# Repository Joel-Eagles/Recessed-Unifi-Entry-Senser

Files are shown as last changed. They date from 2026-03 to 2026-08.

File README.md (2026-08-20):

# Recessed-Unifi-Entry-Senser
A redesigned case for the Ubiquiti SuperLink Entry Sensor. Made to recess the sensor and magnet into the door and frame.

Update: Looks like Ubiquiti saw this and got some ideas. [Click Here](https://store.ui.com/us/en/products/usl-entry-r) to buy the official version

[Click here for IFixit disassembly guide](https://www.ifixit.com/Guide/Ubiquiti+Unifi+Entry+Sensor+%7C+USL-Entry/211997) (Backup is [here](https://github.com/Joel-Eagles/Recessed-Unifi-Entry-Senser/blob/main/DisassemblyGuideBackup.pdf) if unavailable)
<br>
[Click here for the assembly guide](https://github.com/Joel-Eagles/Recessed-Unifi-Entry-Senser/blob/main/Assembly.md)
<br>
[Click here for the installation guide](https://github.com/Joel-Eagles/Recessed-Unifi-Entry-Senser/blob/main/Installation.md)
<br>
[Click here for the onshape source files link](https://cad.onshape.com/documents/9fa11942b709e8cb276eebe3/w/9a96be1a4735a4b981f442b0/e/f783b6d7ffa51d6eca0f374d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)
<br>
[Click here for pre-sliced printable GCode](https://github.com/Joel-Eagles/Recessed-Unifi-Entry-Senser/blob/main/Printable%20STLs/AllParts.gcode.3mf)
<br>
[Click here to download printable STLs](https://github.com/Joel-Eagles/Recessed-Unifi-Entry-Senser/releases/latest/download/allparts.zip)
<br>
[Click here to view the printable files](https://github.com/Joel-Eagles/Recessed-Unifi-Entry-Senser/tree/main/Printable%20STLs)

<br>
<br>

<p>
	
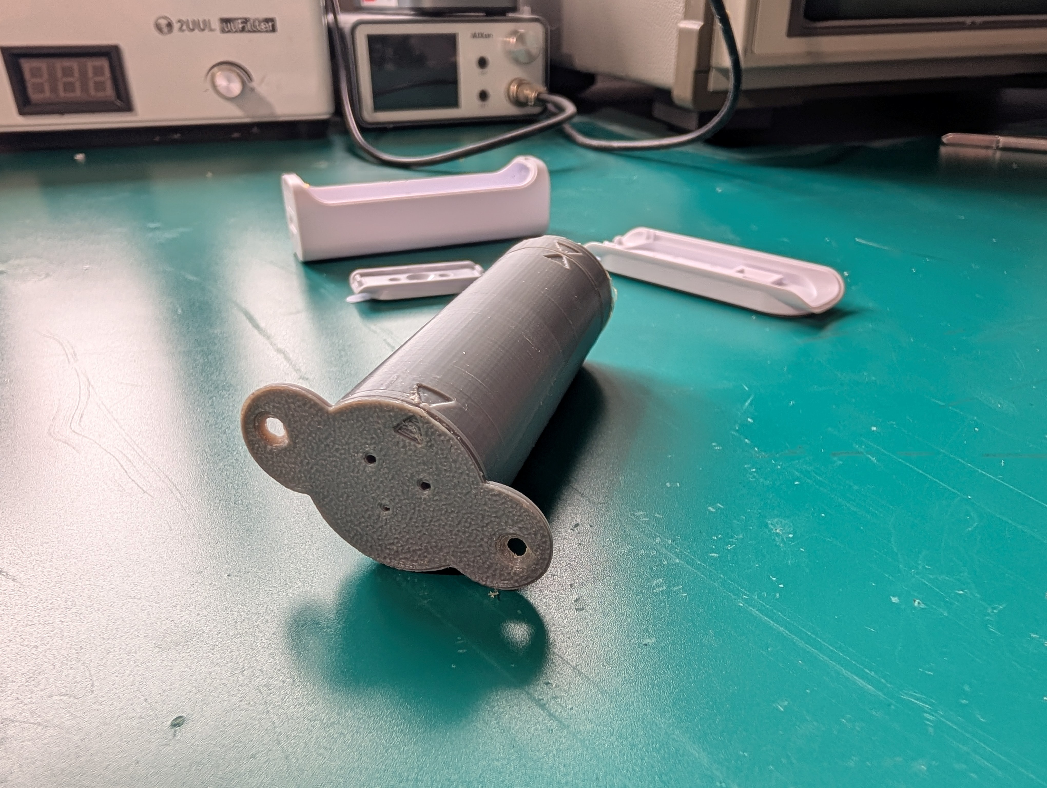
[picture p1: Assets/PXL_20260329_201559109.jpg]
	
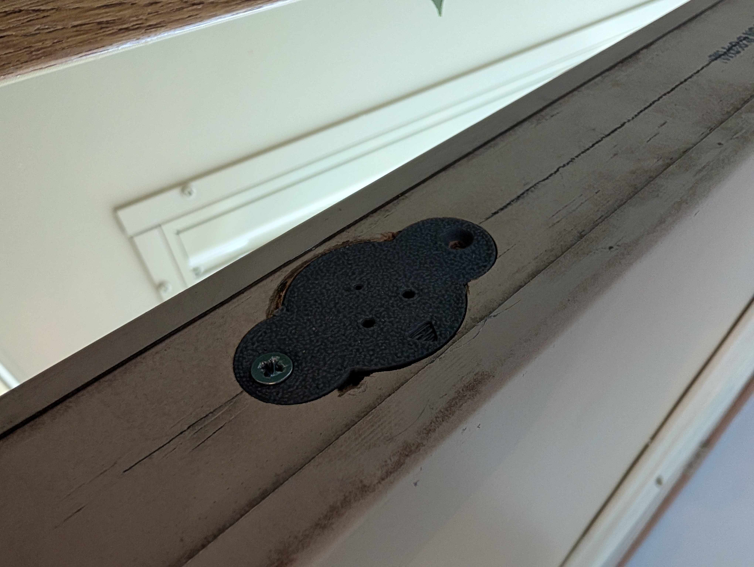
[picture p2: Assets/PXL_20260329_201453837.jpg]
	
</p>

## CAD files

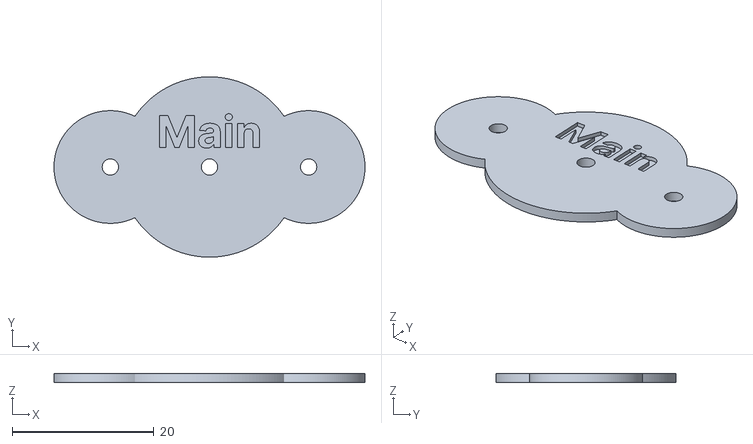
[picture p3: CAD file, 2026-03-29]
Printable STLs/Individual Models/Templates/Main Chassis Template.stl
43.8 x 25.4 x 1.27

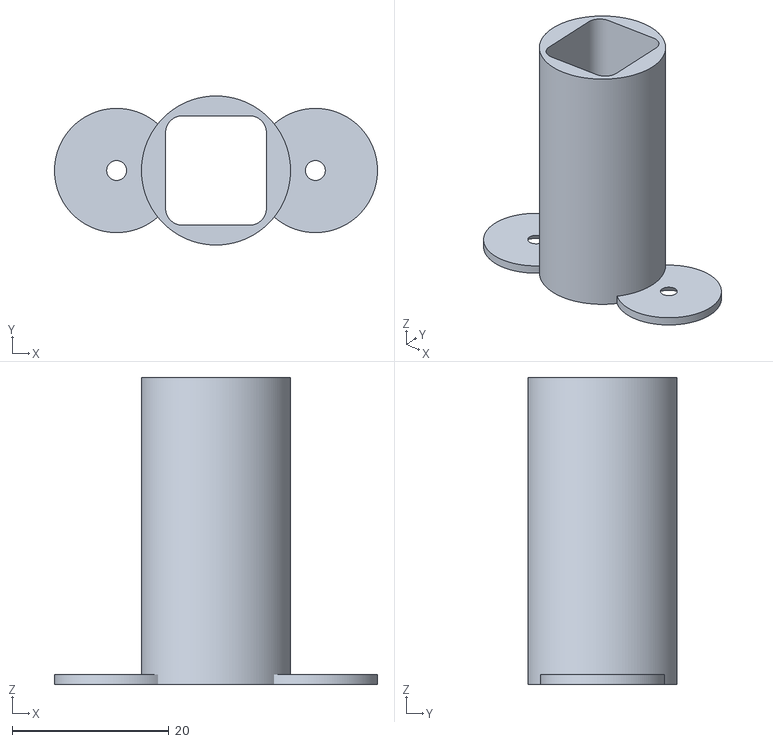
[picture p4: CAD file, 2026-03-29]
Printable STLs/Individual Models/MagnetCase.stl
41.3 x 19.1 x 39.2

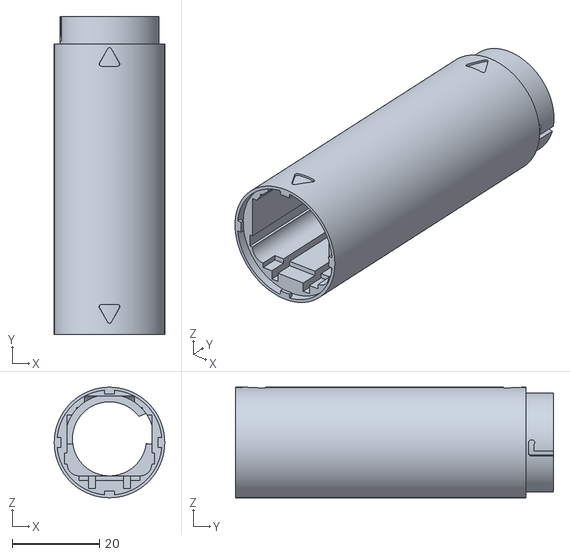
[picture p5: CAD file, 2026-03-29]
Printable STLs/Individual Models/Case.stl
25.4 x 73.1 x 25.4

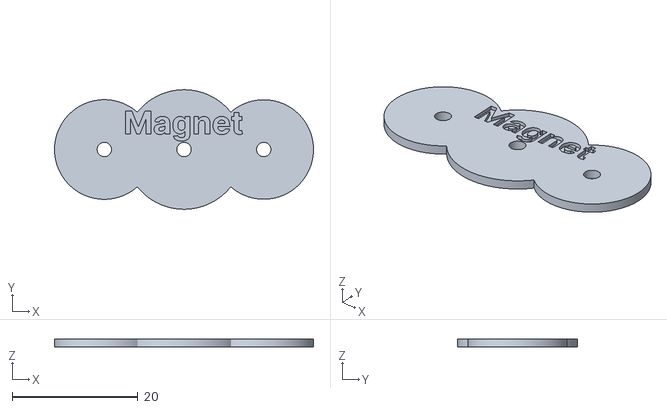
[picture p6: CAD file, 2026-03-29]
Printable STLs/Individual Models/Templates/Magnet Template.stl
41.3 x 19.0 x 1.27

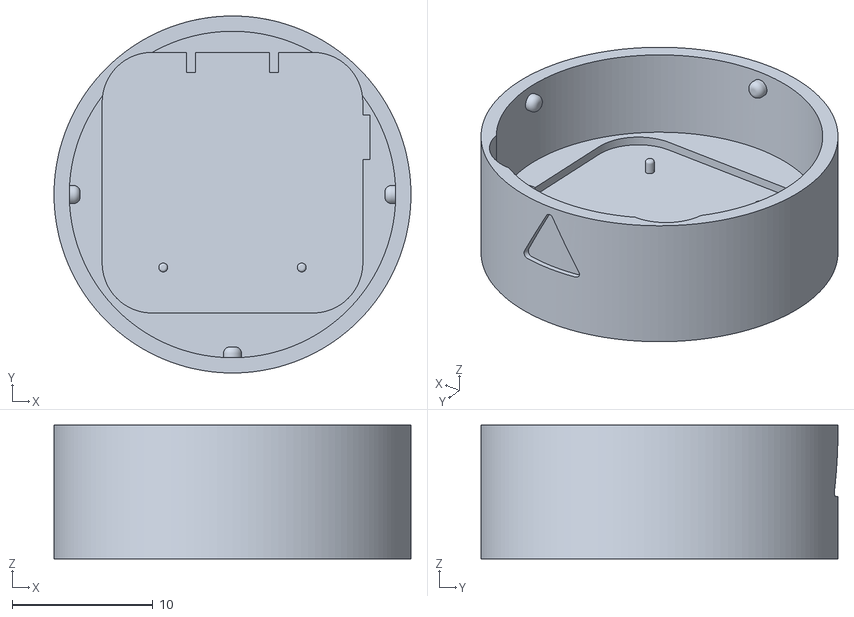
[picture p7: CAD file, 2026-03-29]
Printable STLs/Individual Models/BatteryCap.stl
25.4 x 25.4 x 9.53

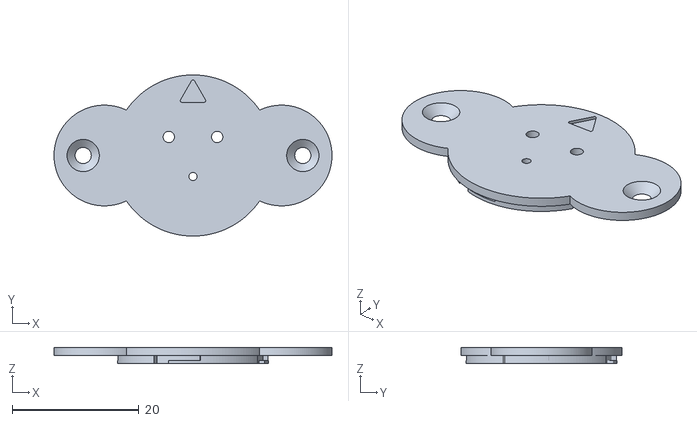
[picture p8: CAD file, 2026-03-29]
Printable STLs/Individual Models/FrontCap.stl
43.8 x 25.4 x 2.54

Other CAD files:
Printable STLs/AllParts.gcode.3mf

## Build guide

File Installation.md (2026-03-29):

[Click here to go home](https://github.com/Joel-Eagles/Recessed-Unifi-Entry-Senser/tree/main)

[Click here for assembly guide](https://github.com/Joel-Eagles/Recessed-Unifi-Entry-Senser/blob/main/Assembly.md)

<br>
<br>

- Mark a centerline along the top of your door
- Align the "Main" Template so that all 3 holes line up with the centerline
  - It is best to position the sensor close to the opening side of the door. This makes it more sensitive to the door opening
- Mark the center point of the 3 circles with a pencil
  - Measure and note the distance from the edge of the door to the center mark. this will be used to position the magnet later. 

<p>
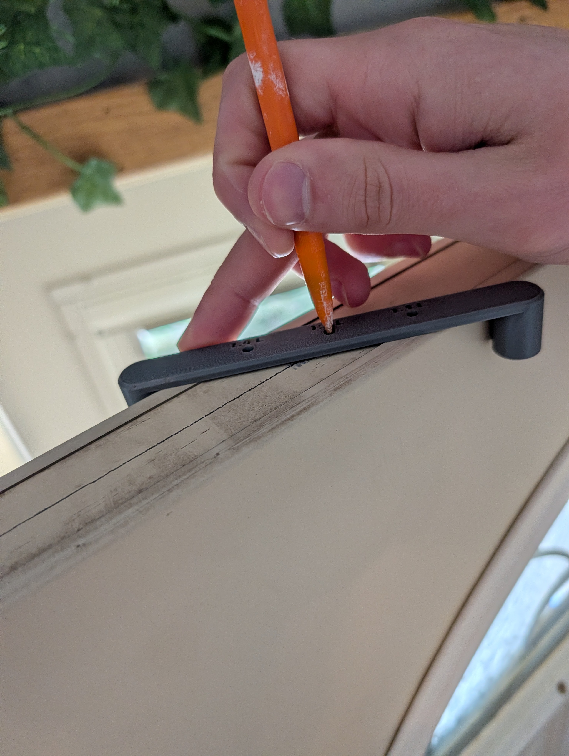
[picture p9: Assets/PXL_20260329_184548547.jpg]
	
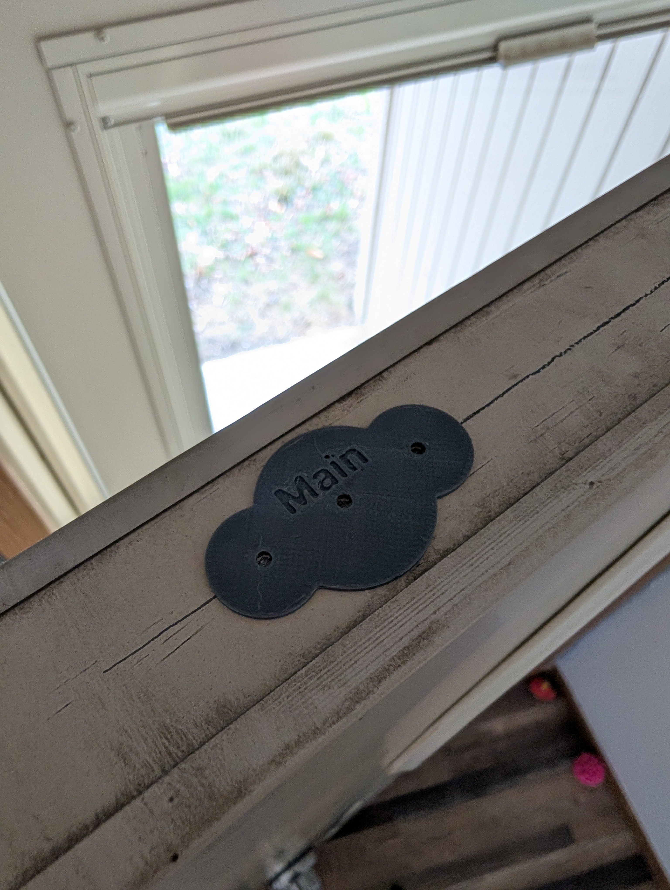
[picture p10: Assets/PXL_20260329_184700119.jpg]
	
</p>

<br>

- With a 5/8" forstner bit, drill on the two outside marks, leaving the 1 in the middle
  - These only need drilled enough to recess the cap into the door, only .05" or about 3/64
  - If you don't mind the look, and your door gap has room for it, you dont have to recesss the cap, and you can skip this step

<p>
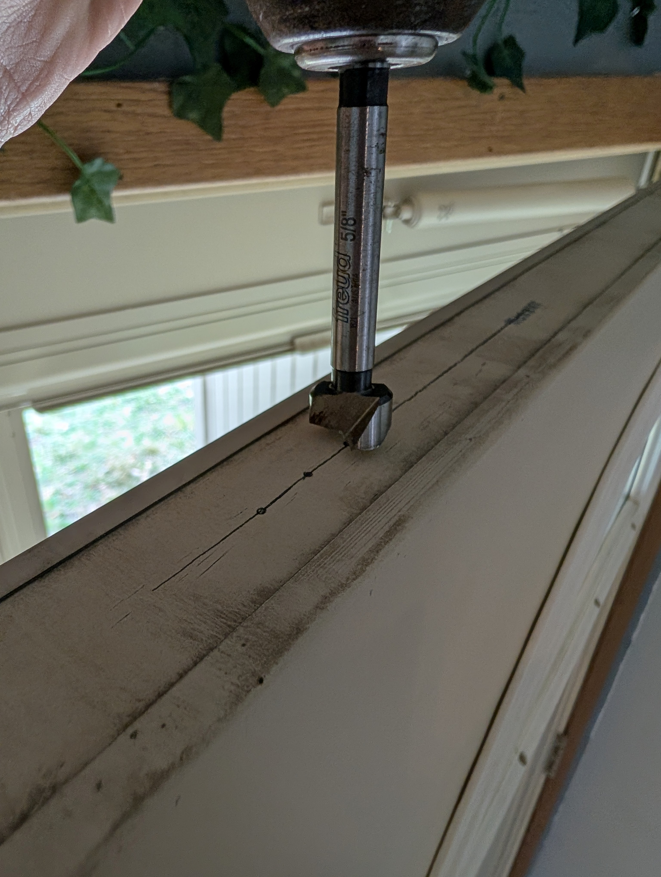
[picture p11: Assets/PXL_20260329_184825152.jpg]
	
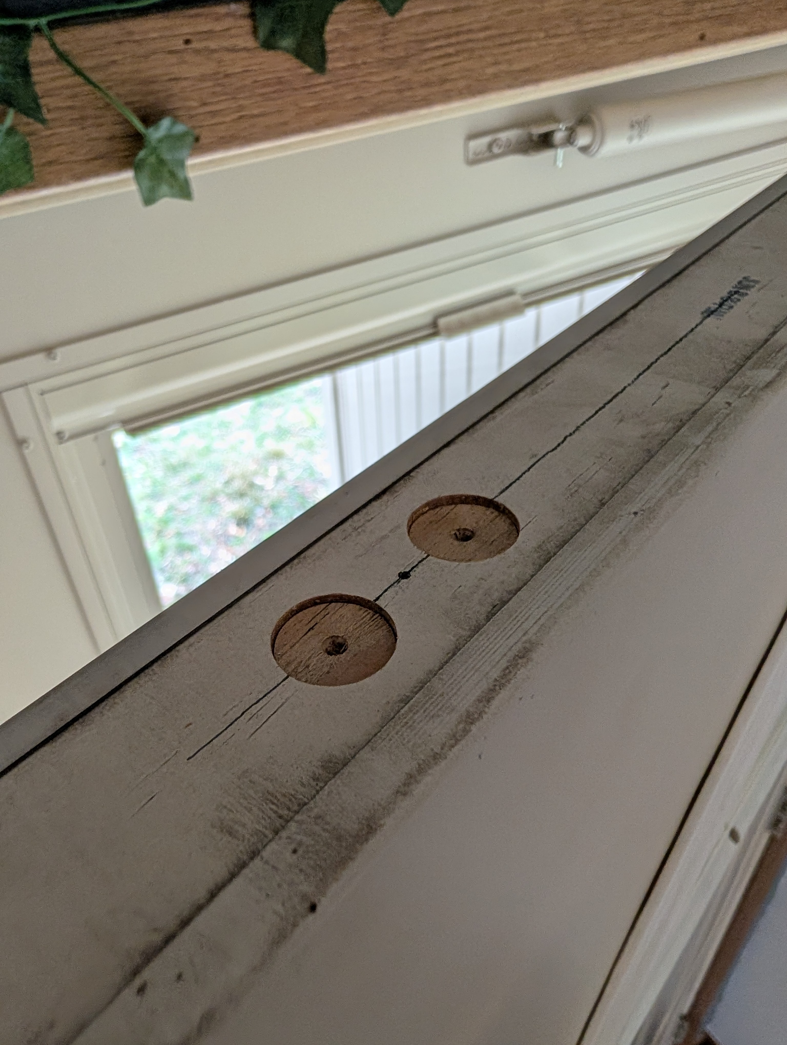
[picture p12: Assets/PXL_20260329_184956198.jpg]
	
</p>

<br>

- With a 1" forstner bit, dill out the center mark.
  - mark the depth you need to drill by lining up the sensor case with your drill bit and mark the end with a tape flag (add a small amount extra for safety).

<p>
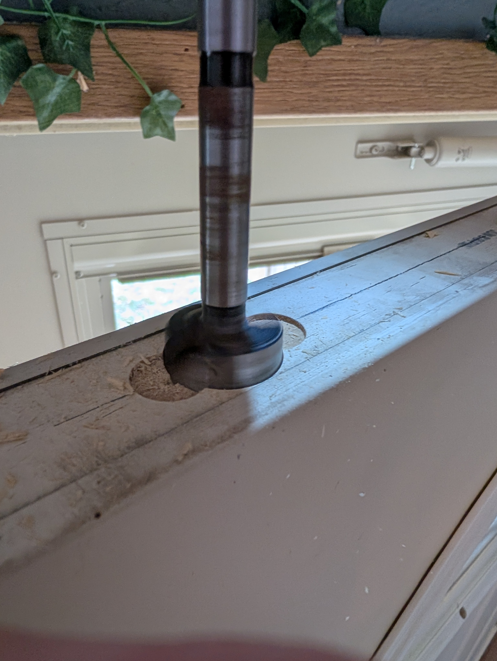
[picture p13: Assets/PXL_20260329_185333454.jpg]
	
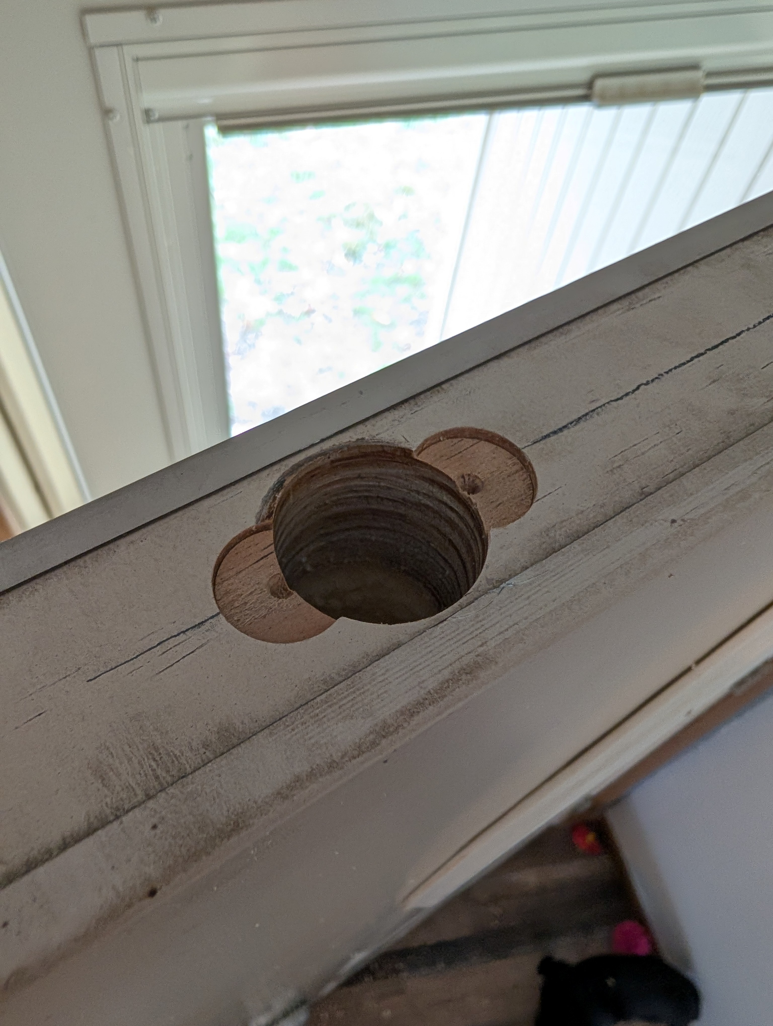
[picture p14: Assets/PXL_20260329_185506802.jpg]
	
</p>

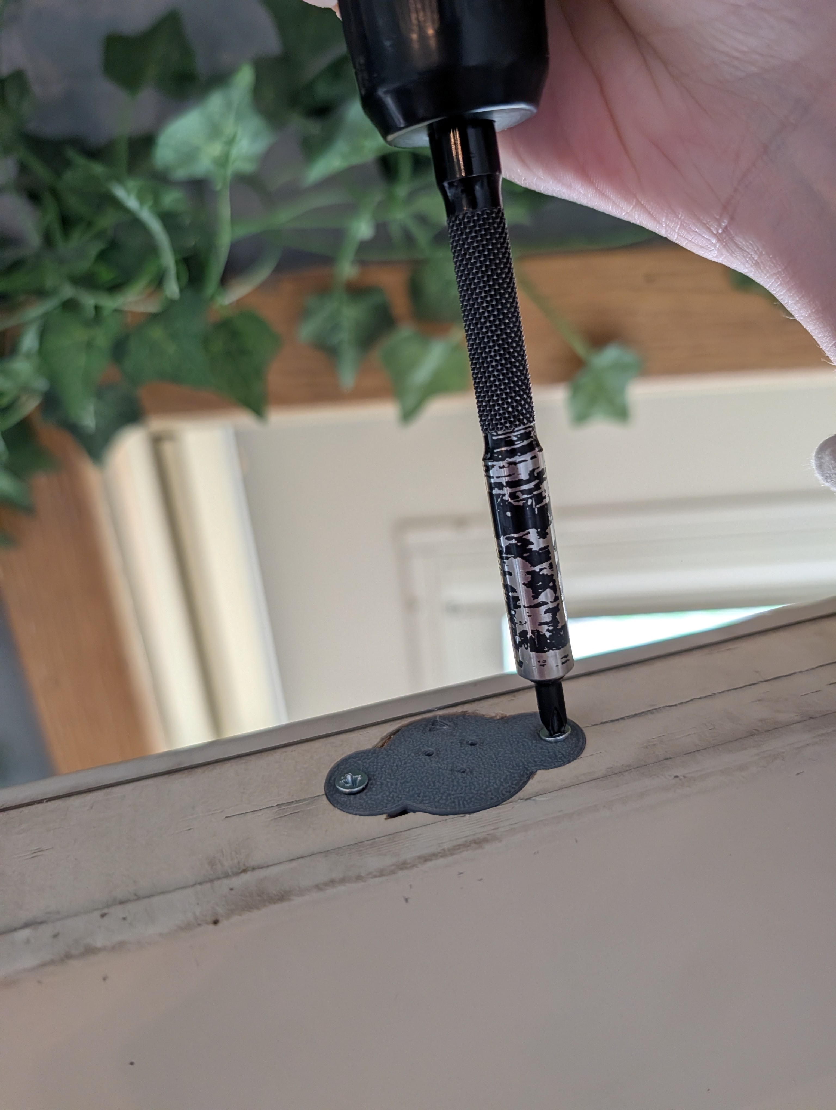
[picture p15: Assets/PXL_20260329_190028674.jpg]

<br>
<br>
<br>
<br>
<br>
<br>

- Slide in sensor and screw in through the ears.
  - I used some #4x1/2" wood screws for this

<br>
<br>
<br>
<br>
<br>
<br>
<br>
<br>
<br>

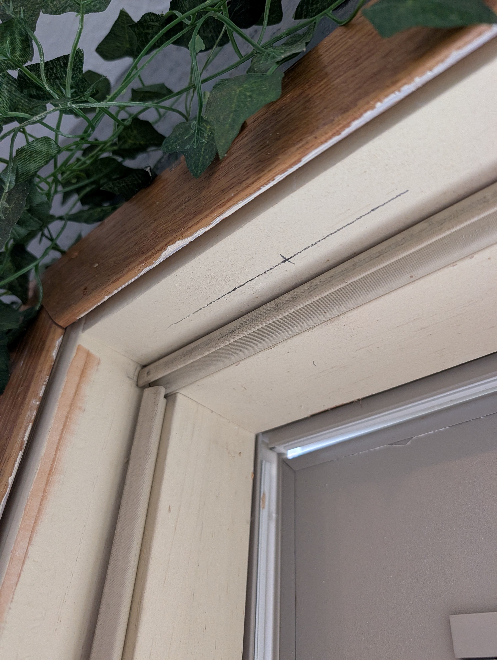
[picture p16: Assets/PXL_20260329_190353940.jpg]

<br>
<br>
<br>
<br>
<br>
<br>

- Take the sensor's distance from the outside face of your door (should be half the thickness of your door). Mark this on the top of the door casing off of the door stop molding
- Take the distance from of the edge of the door and add the width of your door's gaps (close the door and measure the distance from the door edge to the door casing). mark this distance on the top of the door casing off of the door jam.

<br>
<br>
<br>
<br>
<br>
<br>
<br>
<br>
<br>

- Align the center hole of the "Magnet" template with the intersecting lines you just marked on the top of the door casing.
- mark the 2 outer circle centers

  <p>
	
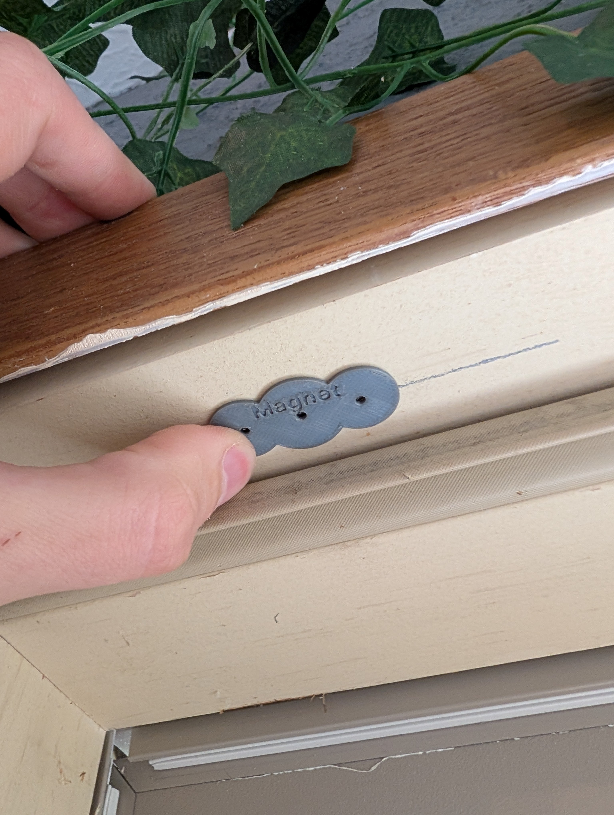
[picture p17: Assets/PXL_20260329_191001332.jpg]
	
</p>

<br>

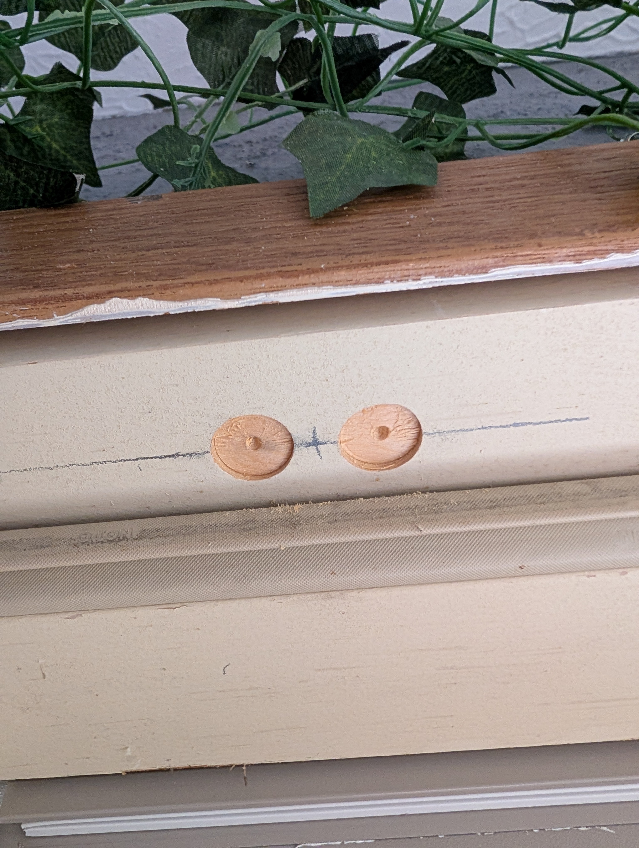
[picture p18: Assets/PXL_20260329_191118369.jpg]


<br>
<br>
<br>
<br>
<br>
<br>

- With a 5/8" forstner bit, drill on the two outside marks, leaving the 1 in the middle
  - These only need drilled enough to recess the cap into the door, only .05" or about 3/64
  - If you don't mind the look, and your door gap has room for it, you dont have to recesss the cap. and you can skip this step

<br>
<br>
<br>
<br>
<br>
<br>
<br>
<br>

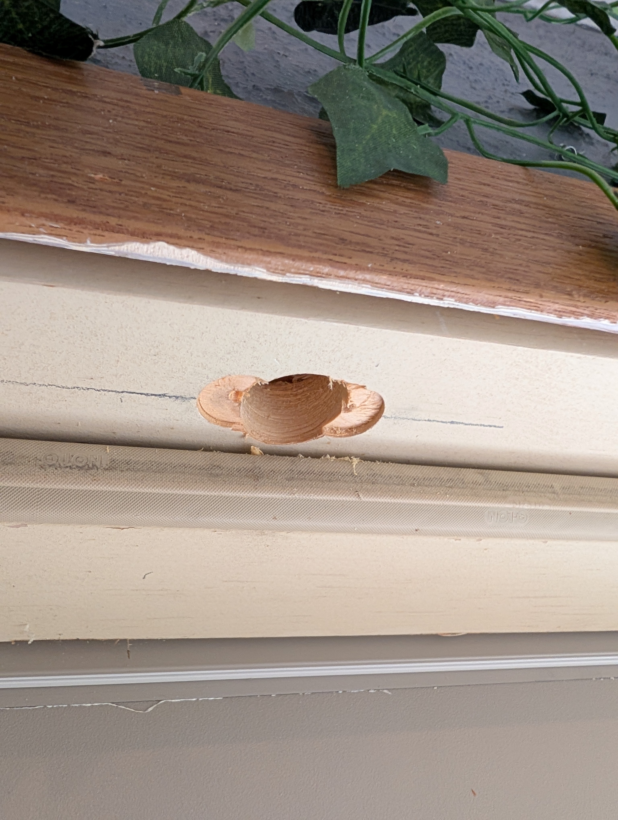
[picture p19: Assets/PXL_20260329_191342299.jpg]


<br>
<br>
<br>
<br>

- With a 3/4" forstner bit, dill out the center mark.
  - mark the depth you need to drill by lining up the magnet case with your drill bit and mark the end with a tape flag (add a small amount extra for safety).

<br>
<br>
<br>
<br>
<br>
<br>
<br>
<br>
<br>

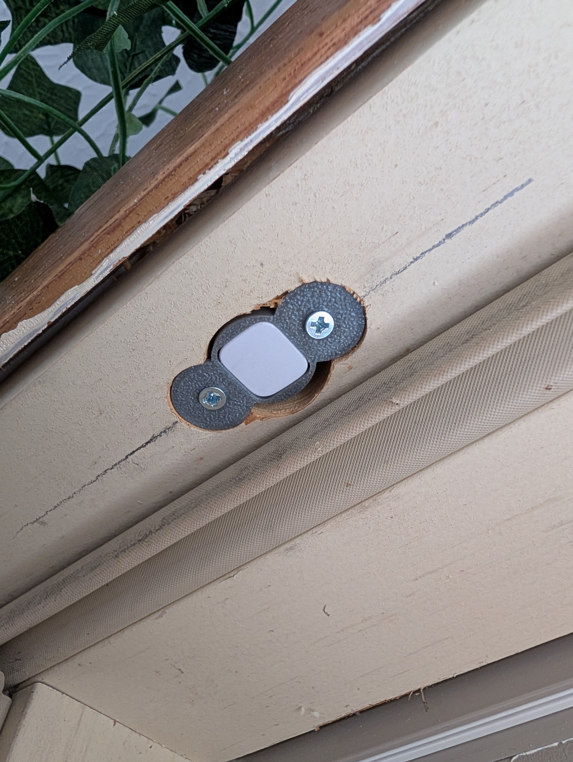
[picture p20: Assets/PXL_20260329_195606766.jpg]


<br>
<br>
<br>
<br>
<br>
<br>

- Slide in Magnet and screw in through the ears.
  - I used some #4x1/2" wood screws for this

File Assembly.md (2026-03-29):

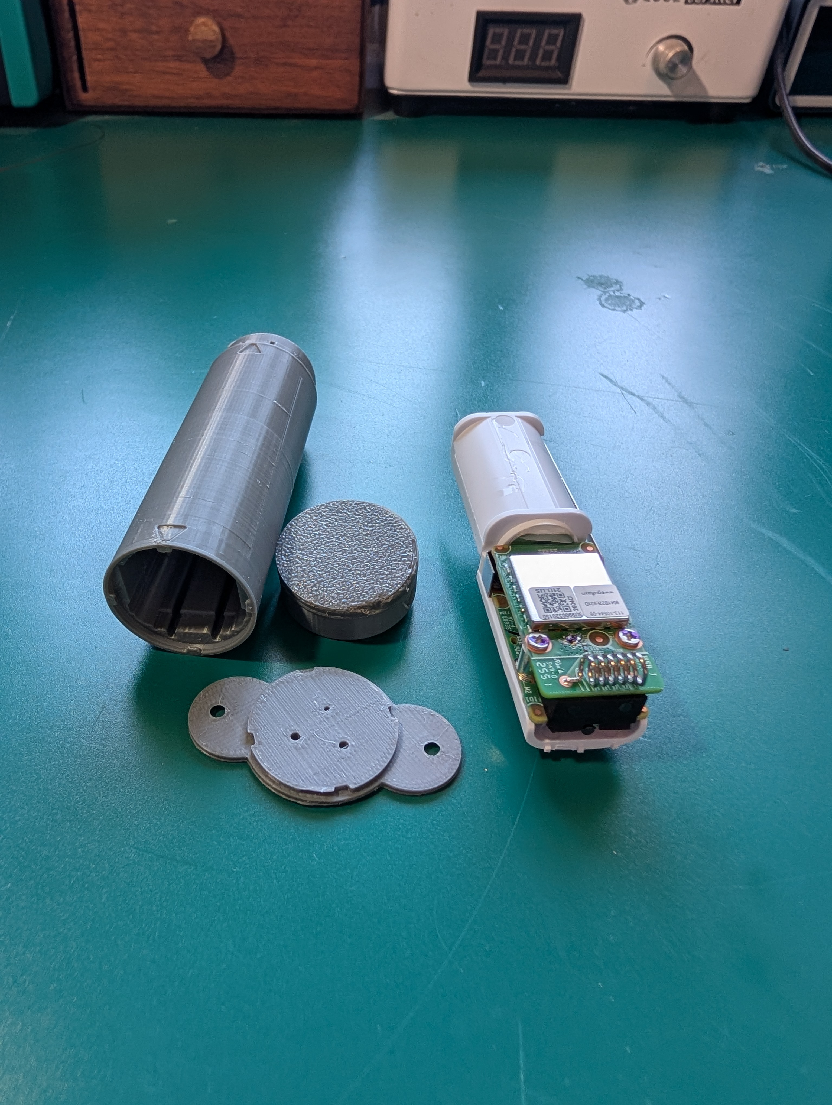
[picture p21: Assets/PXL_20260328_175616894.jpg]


[Click here to go back](https://github.com/Joel-Eagles/Recessed-Unifi-Entry-Senser/tree/main)
<br>
<br>

- Start by disassembling the sensor. I have an [IFixit guide](<https://www.ifixit.com/Guide/Ubiquiti+Unifi+Entry+Sensor+%7C+USL-Entry/211997>) that details this process. Follow the guide up to step 5.
  
<br>
<br>
<br>
<br>

- Next, trim the small plastic bumps along the Battery holder on the main body.
	- use a pair of flush cutters to cut off the bumps.

<p>
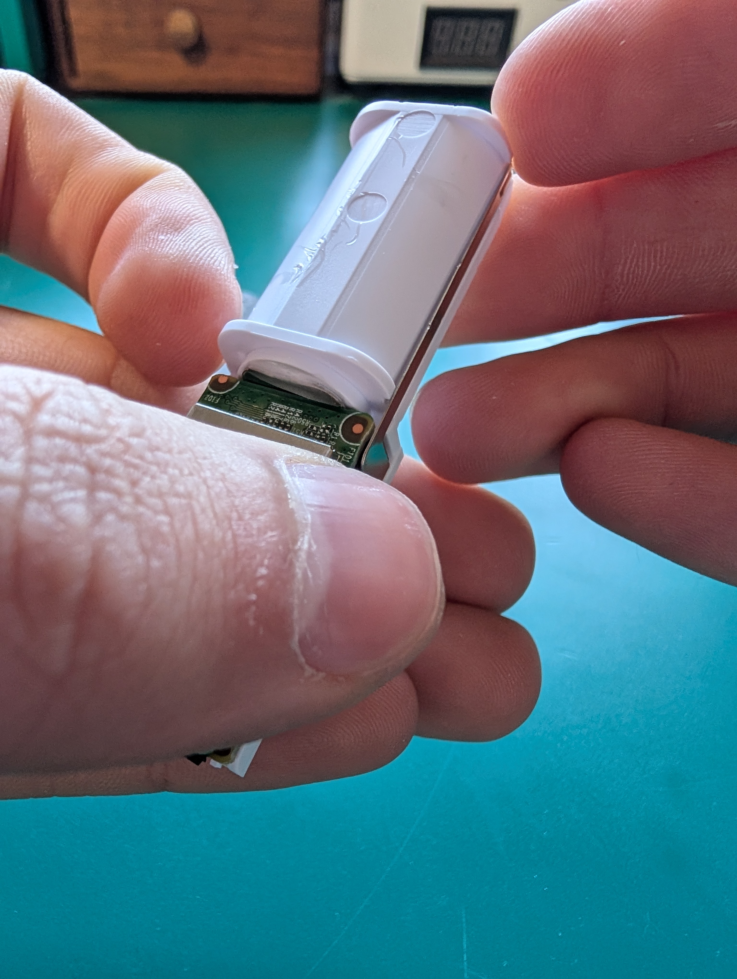
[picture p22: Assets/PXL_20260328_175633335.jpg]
	
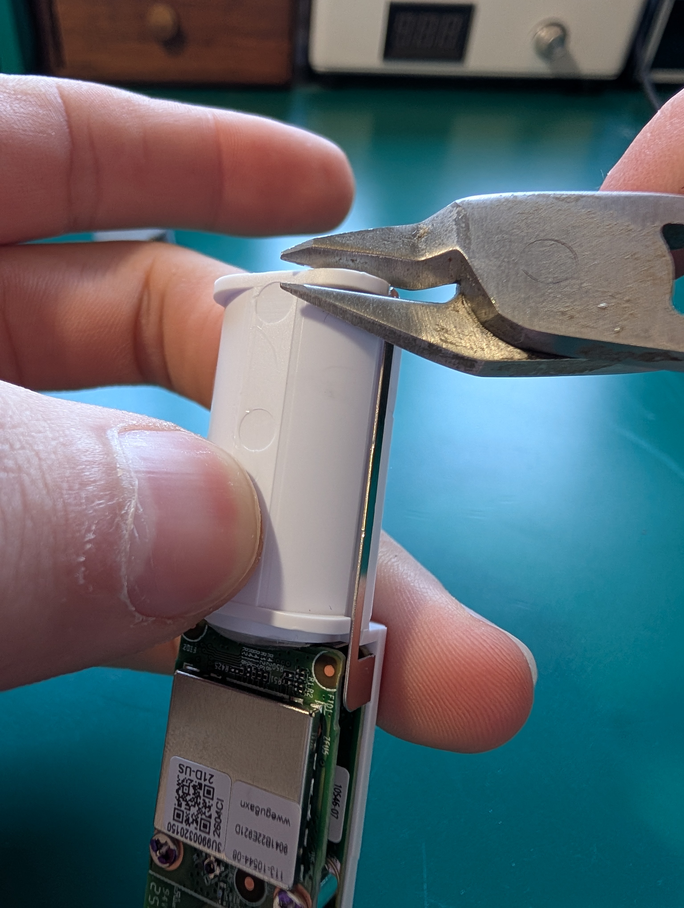
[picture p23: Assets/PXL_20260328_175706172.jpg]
	
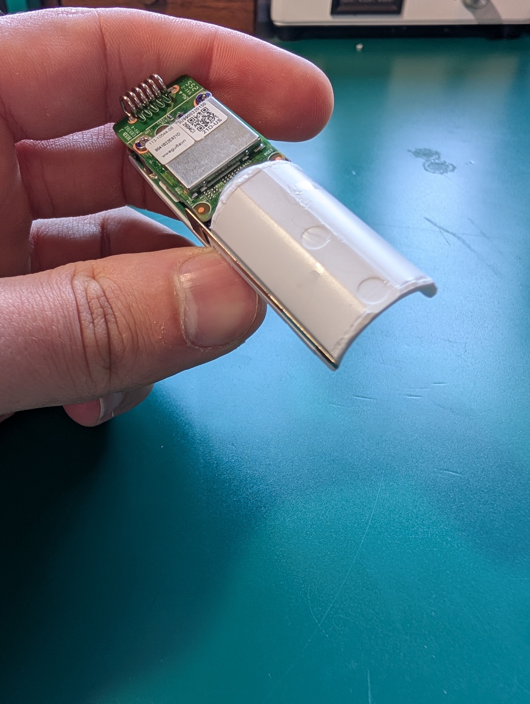
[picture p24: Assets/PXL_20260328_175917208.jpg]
	
</p>

- Insert your sensor main body into the 3d printed case.
	- Make sure to align the 2 parallel slots with the plastic clips on the bottom of the main body.

<p>
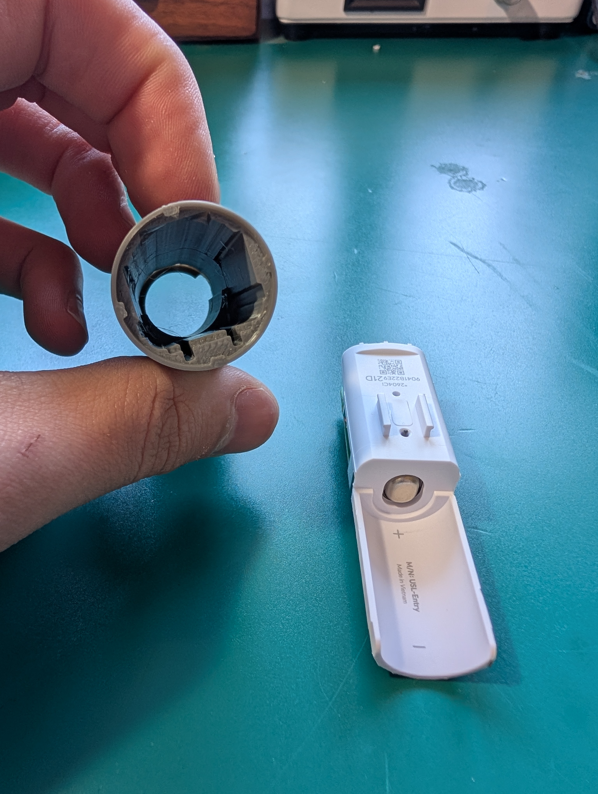
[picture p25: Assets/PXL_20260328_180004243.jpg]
	
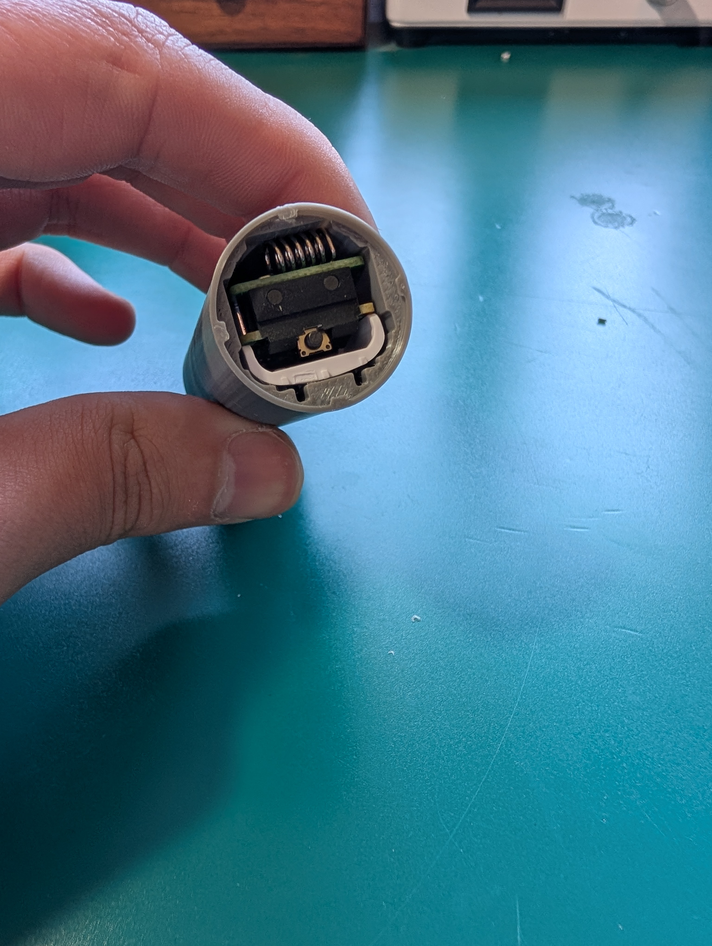
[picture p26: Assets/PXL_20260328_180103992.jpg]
	
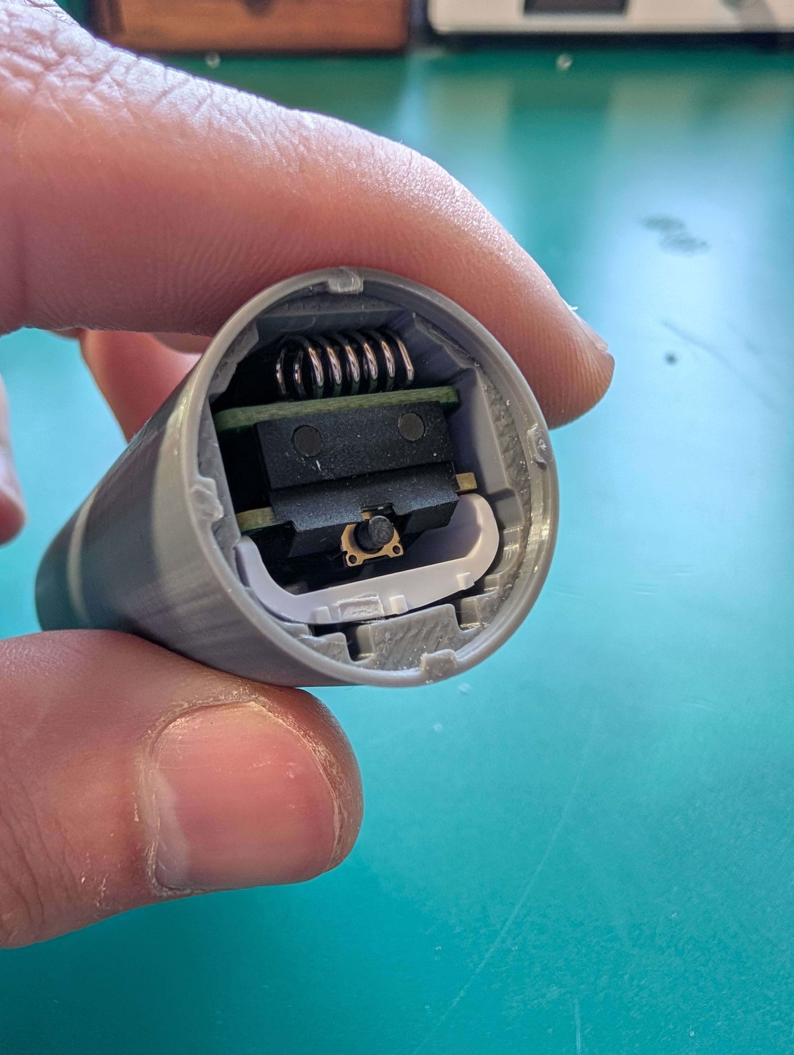
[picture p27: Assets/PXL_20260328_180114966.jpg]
	
</p>

- Align the front twist-cap with the locking pegs, and turn clockwise to lock it into place.
	- The two alignment marks should line up once fully seated.

<p>
	
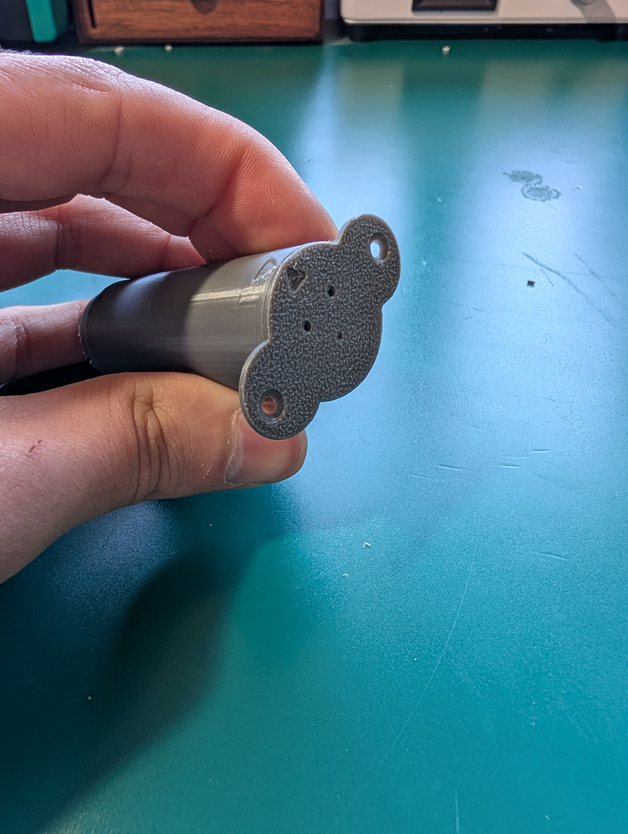
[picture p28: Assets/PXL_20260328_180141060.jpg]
	
</p>
   
- Flip the case and push the battery into the hole, fully seat.
- Place the negative battery contact into the rear twist-cap.
	- the contact plate has cutouts on the bottom edge and holes above the spring contact. The rear twist cap has matching features to help align it properly
 	- you will have wanted to keep the adhesive on the back of the contact plate.
 
<p>
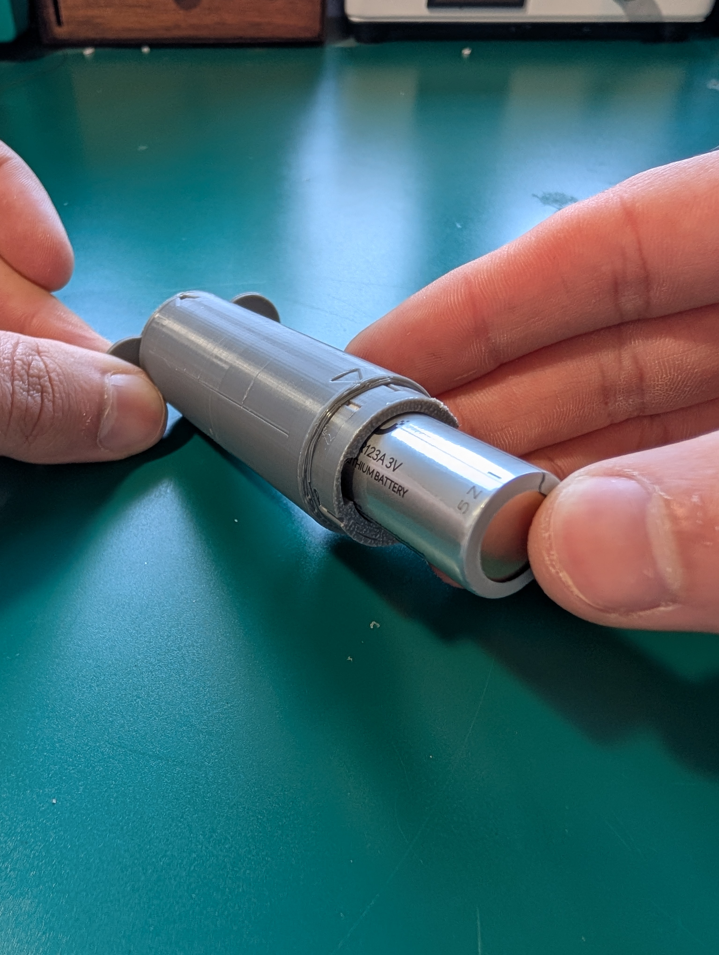
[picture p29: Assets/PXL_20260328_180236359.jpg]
	
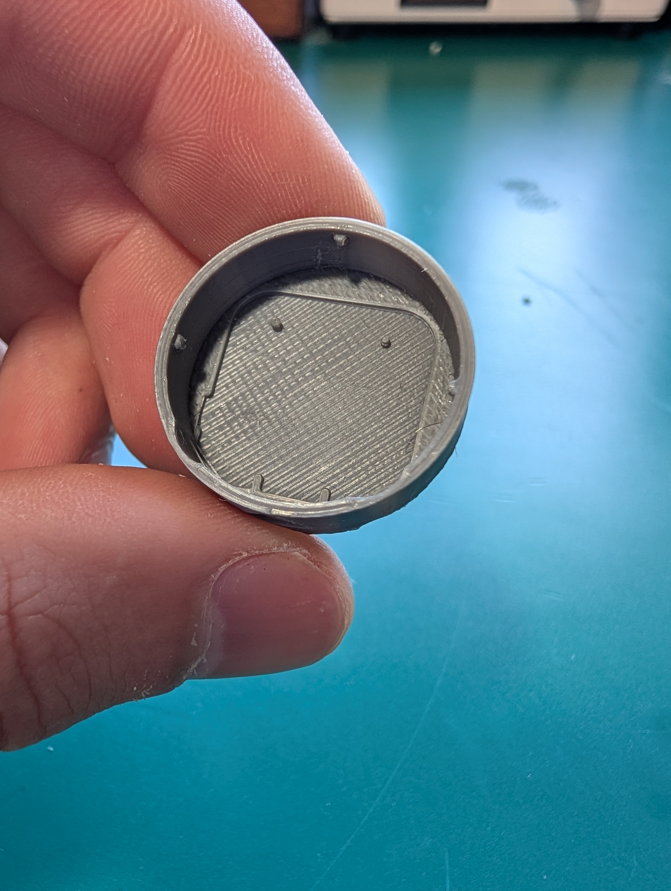
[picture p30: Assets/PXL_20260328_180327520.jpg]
	
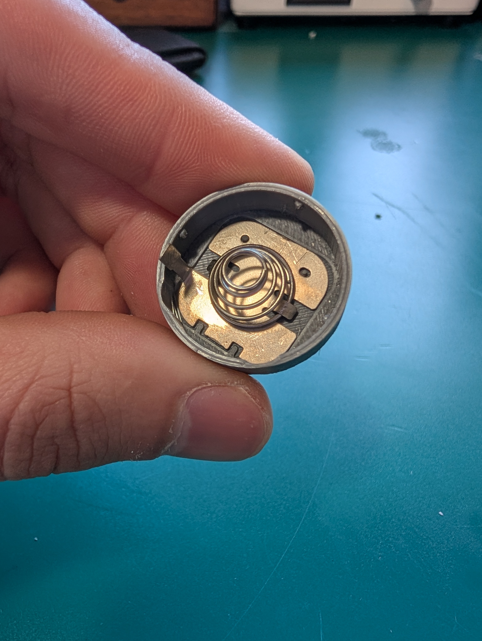
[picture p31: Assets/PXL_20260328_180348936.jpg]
	
</p>
	
- Align the battery contact connector pin with the corresponding notch in the main case.
- Align the nubs in the cap with the slots in the main case, then push the cap down and twist clockwise to lock it in place.
	- If the metal connector pin on the battery contact binds or snags while pressing or twisting the cap into place, you may need to gently bend the pin outward so that it presses lightly against the wall of the main shell
- you should see the power LED on the face turn on within 5 seconds

<p>
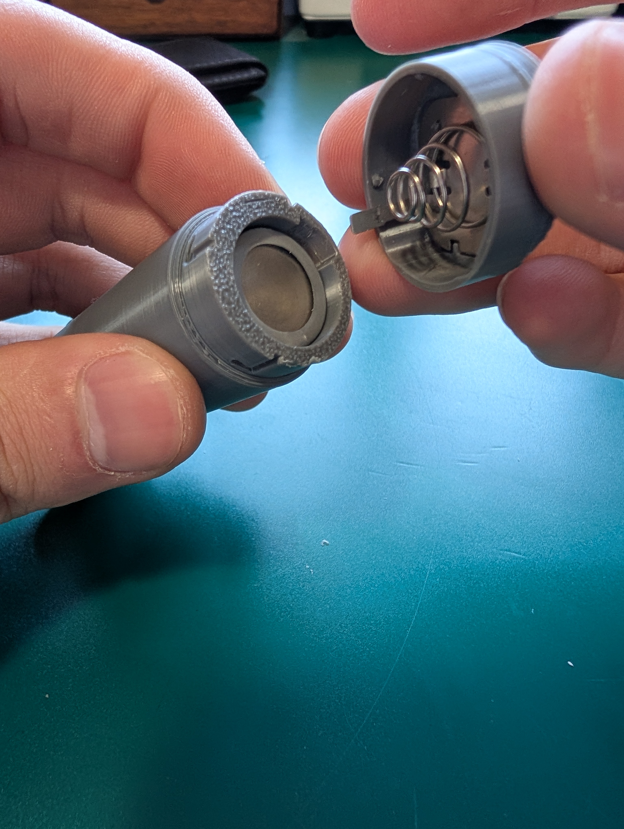
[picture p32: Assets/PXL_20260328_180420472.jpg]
	
	
</p>

<br>
<br>
<br>

 - Now move on to the magnet.
 - Remove the back cover using the included tool.
 	- I attempted to remove the magnet from its case, but was unsuccessful. soaking in alcohol and heating with a rework station did not loosen the adhesive at all.

   <p>
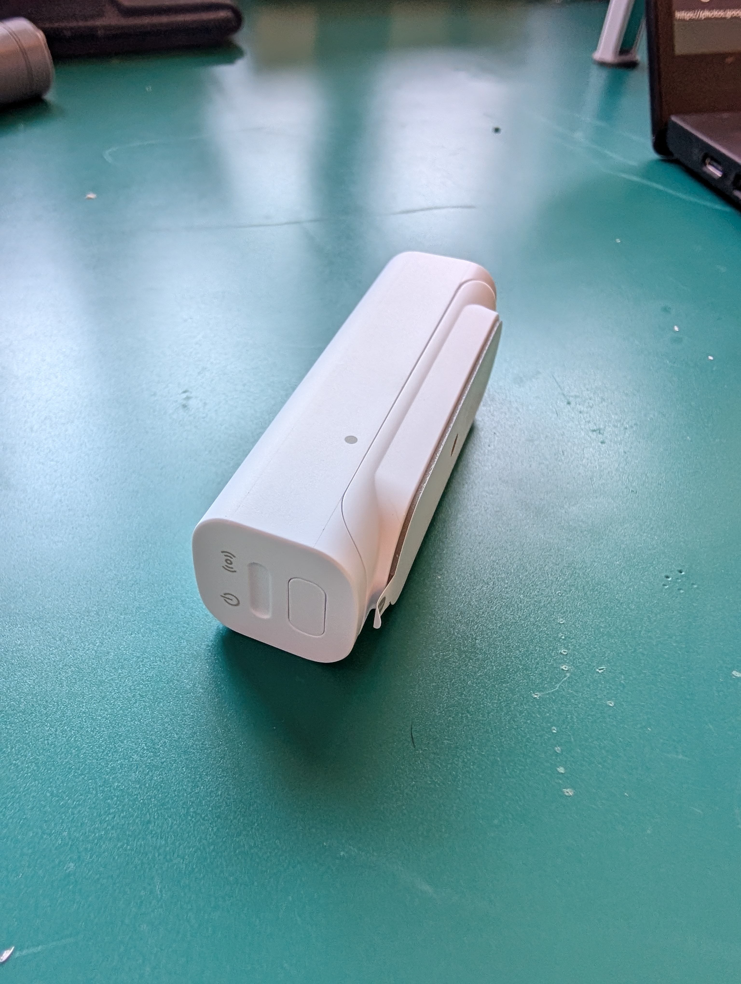
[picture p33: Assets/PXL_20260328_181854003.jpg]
	
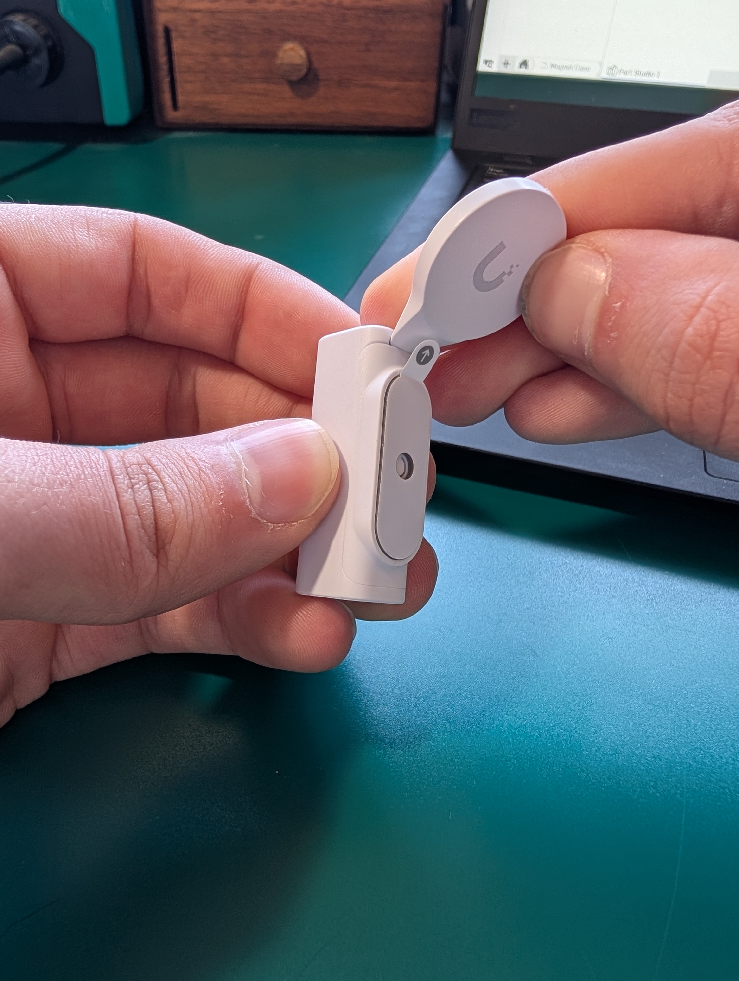
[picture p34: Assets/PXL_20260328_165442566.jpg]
	
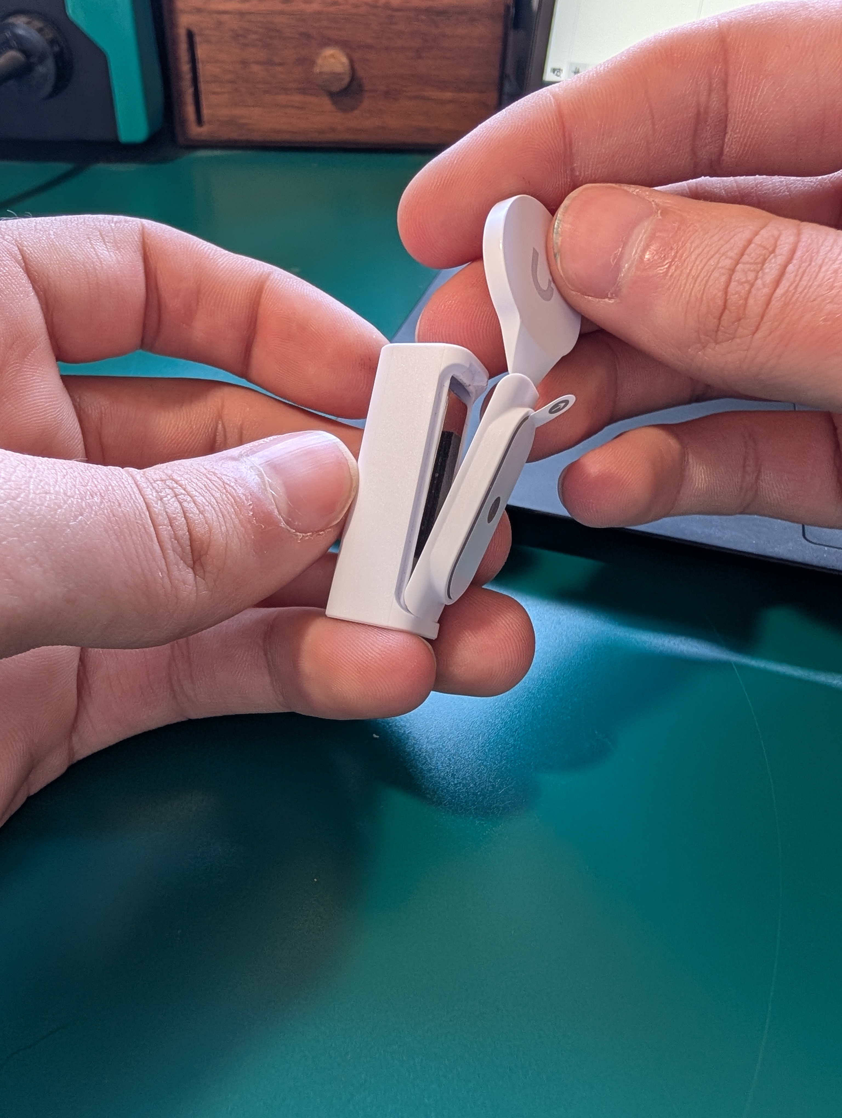
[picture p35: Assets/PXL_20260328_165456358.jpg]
	
</p>

 - Press the magnet with its case into the new shell

<p>
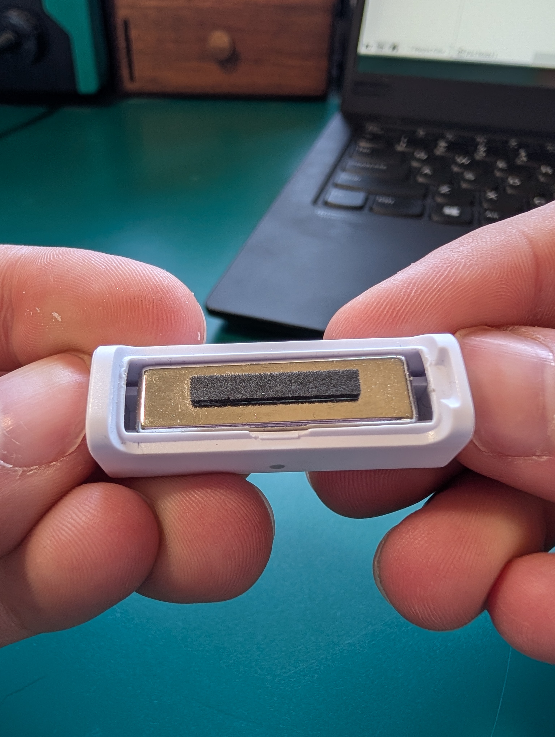
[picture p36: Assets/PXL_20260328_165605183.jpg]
	
	
</p>

<div align="right">
	
  [Click here for instalation guide](https://github.com/Joel-Eagles/Recessed-Unifi-Entry-Senser/blob/main/Installation.md)
</div>

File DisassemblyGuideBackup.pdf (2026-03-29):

## Ubiquiti Unifi Entry Sensor | USL-Entry

Unifi Protect SuperLink sensor with up to...
Written By: Joel Eagles

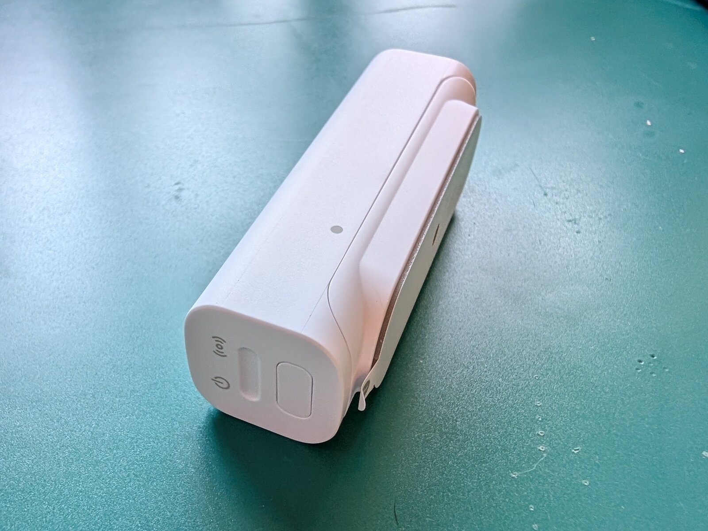
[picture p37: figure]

INTRODUCTION

Unifi Protect SuperLink sensor with up to 6-year battery life for monitoring door and window open/closed status.

TOOLS:
Phillips #1 Screwdriver (https://www.ifixit.com/products/phillips-1-screwdriver) (1) Phillips #0 Screwdriver (https://www.ifixit.com/products/phillips-0-screwdriver) (1) Hot air rework tool (1)
Pick Tool (https://www.amazon.com/TEKTON-6943-Precision-Pick-4-Piece/dp/B000NPPBQK) (1)
Tweezers (https://www.ifixit.com/products/tweezers) (1)
Step 1 — Battery Cover

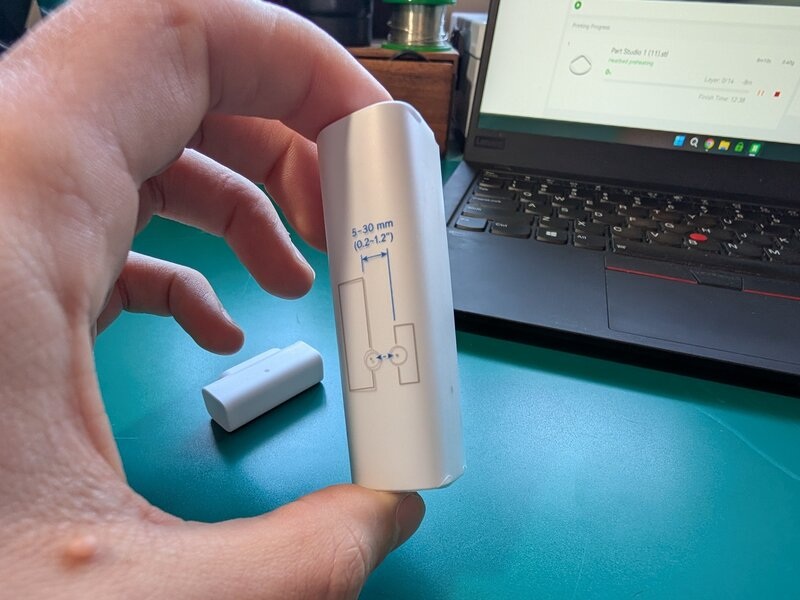
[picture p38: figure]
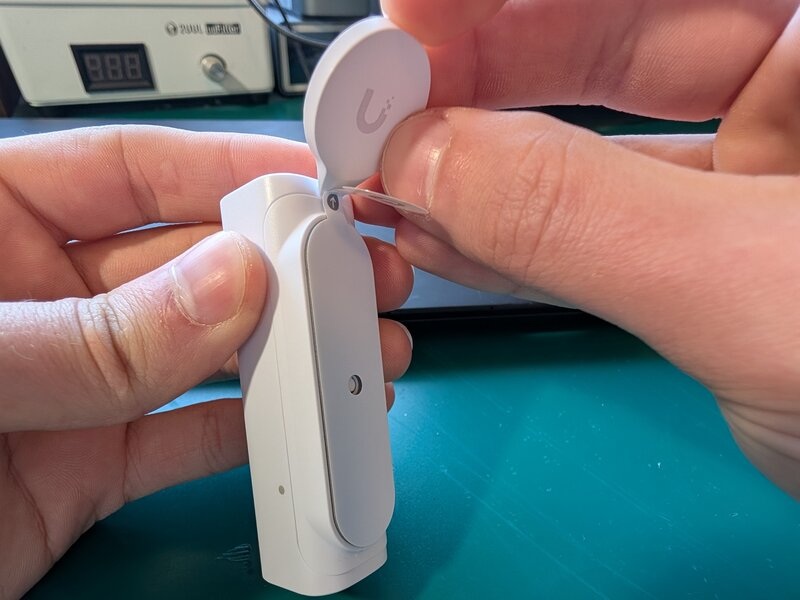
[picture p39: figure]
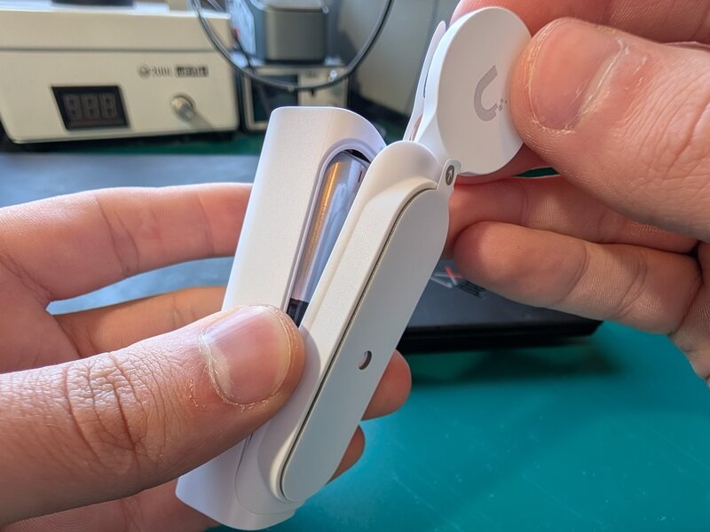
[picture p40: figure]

Begin by removing the battery cover. Use the included tool to pop off the edge, then pry outwards to disconnect the large plastic clips that are further down.

Step 2 — Outer Shell Removal

To remove the inner body from the outer shell, you will have to get it around both the battery connectors and the two plastic retaining clips at the center.

You can pull on the outer walls to move the plastic clips out of the way, then push a metal pick behind the edge of the inner body by the battery holder.

Step 3 — Outer Shell Removal Continued

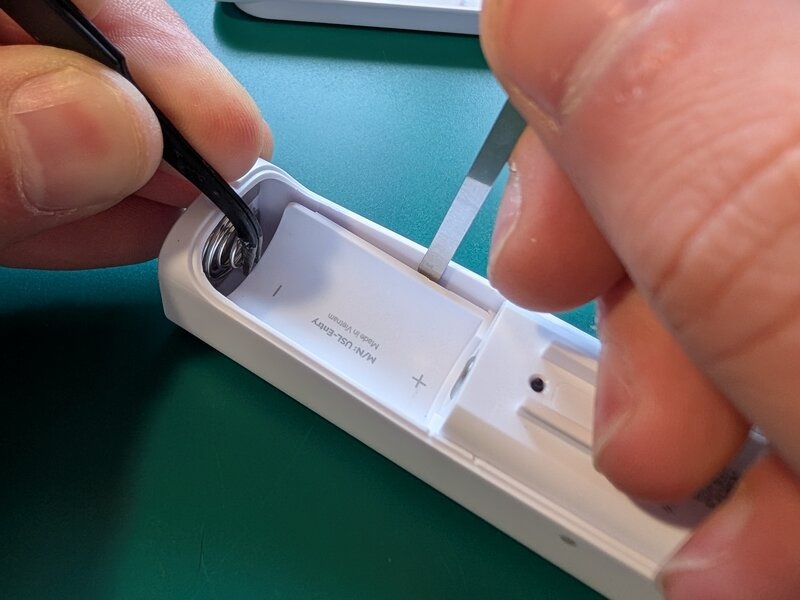
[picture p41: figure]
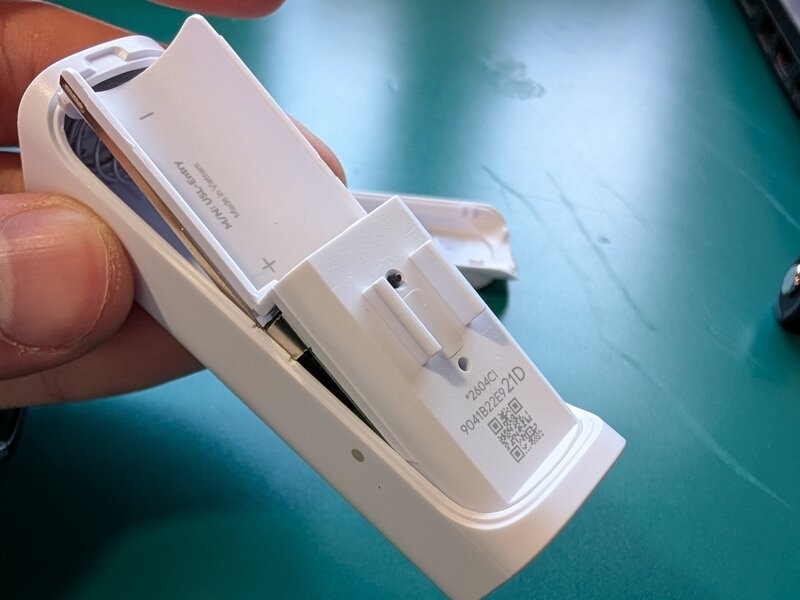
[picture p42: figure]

Depress the battery contact spring out of the way as you pry the inner body out. once you get the edge of the battery holder past the contact spring, it should lift out easily.

The button face will fall out naturally as it is not held in with anything except the pressure of the button behind it

Step 4 — Negative Battery Contact Removal

The battery contact is held on with adhesive tape. I was not able to separate it from the shell with prying alone.

I used a hot air rework station set to 300°F 149°C at max air speed. I heated the metal directly until it was heat-soaked, about 1 minute

I used a sharp pair of tweezers in the corner to pry the contact off the back shell while it was still hot

Make sure you don't pry hard enough to bend the metal

Step 5 — Basic Disassembly Complete

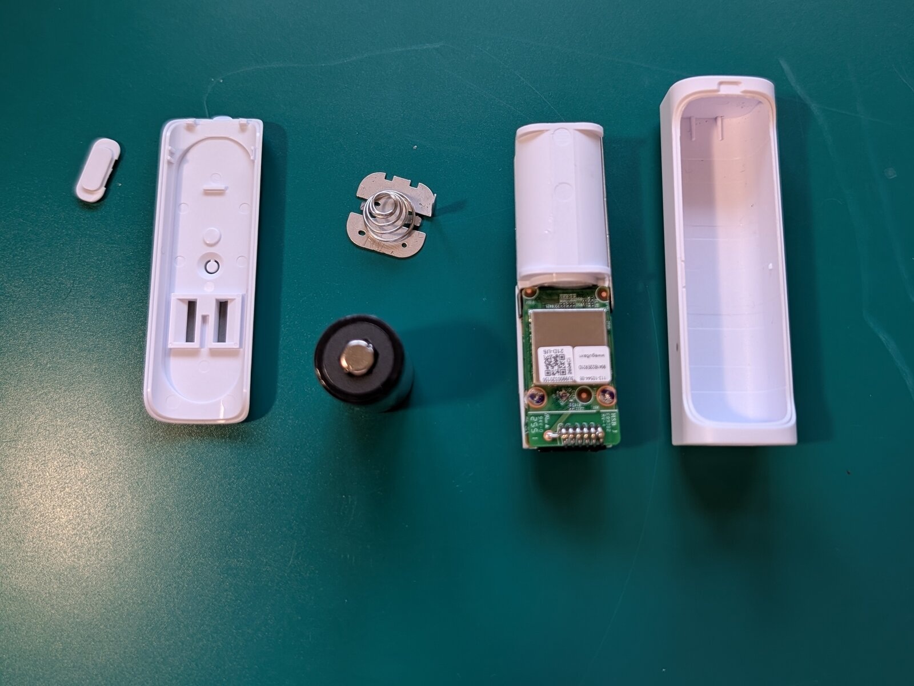
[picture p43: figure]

The main body is now free
from the outer chassis

Step 6 — Upper PCB Removal

Unscrew the 2 Phillips #1 screws near the wireless antenna

Scrape off any glue holding the top PCB near the battery contact

Gently pull the top PCB directly upward to disconnect it from the connector on the bottom PCB

Step 7 — Lower PCB and Battery Contact Removal

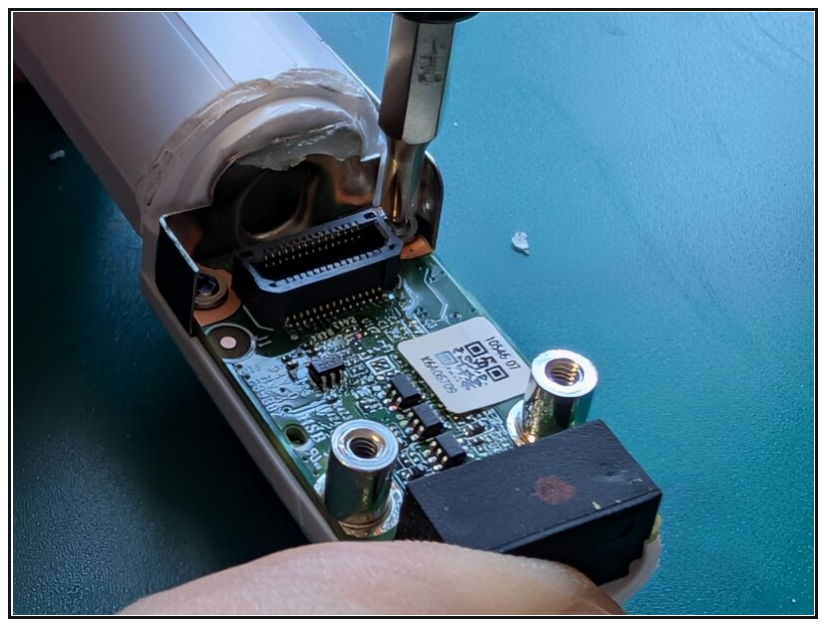
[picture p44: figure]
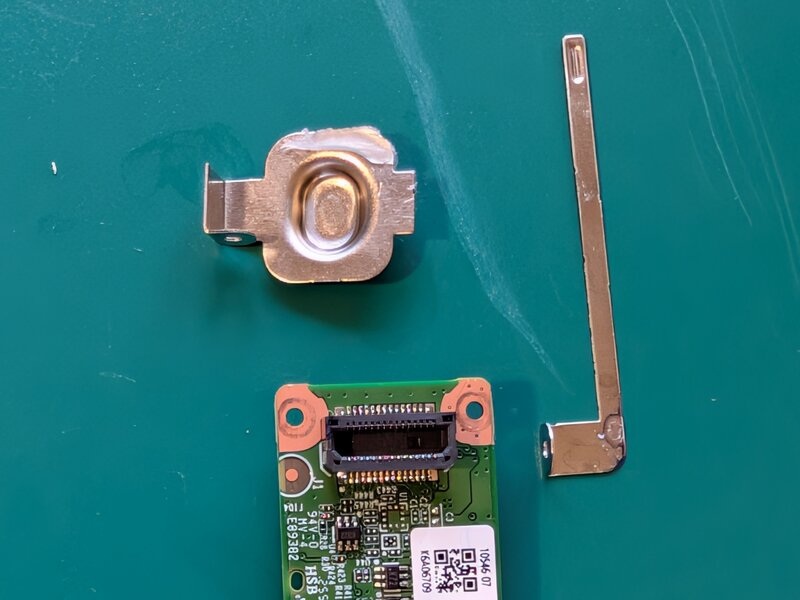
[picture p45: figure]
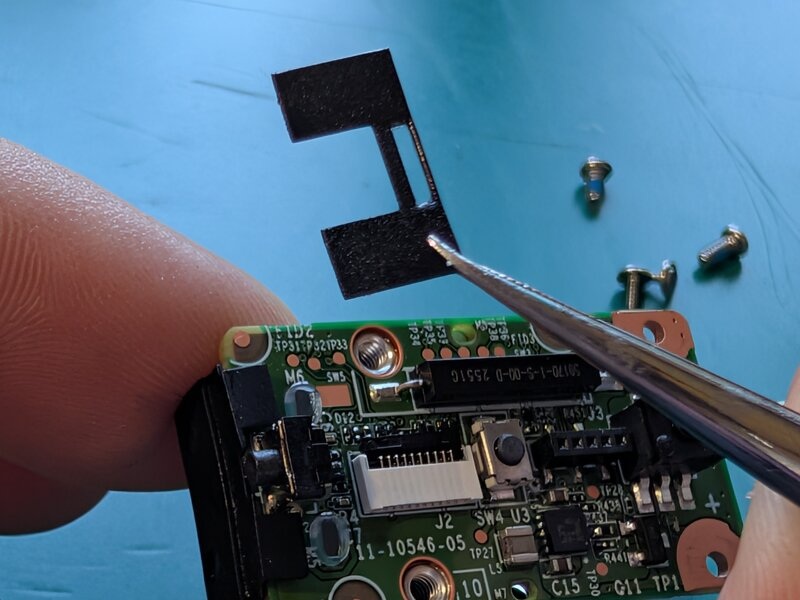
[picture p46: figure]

Remove the 2 Phillips #0 screws near the battery connector. these screws are holding the PCB down, as well as holding the battery contacts against the board's power inputs

A small adhesive-backed plastic cover wraps around the button on the end of the PCB, and covers the plastic welds of the LED light pipes to prevent light leaks. it sits under the rubber light pipe cover

To reassemble your device, follow these instructions in reverse order.

Step 8 — Light Pipe Exposure

you can now gently remove the rubber light pipe cover to further expose the LEDs and their light pipes

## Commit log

2026-03-29 Rename FrontCap.stl to Printable STLs/Individual Models/FrontCap.stl
    [FrontCap.stl]
2026-03-29 Rename Printable STLs/Individual Models/Magnet Template.stl to Printable STLs/Individual Models/Templates/Magnet Template.stl
    [Magnet Template.stl]
